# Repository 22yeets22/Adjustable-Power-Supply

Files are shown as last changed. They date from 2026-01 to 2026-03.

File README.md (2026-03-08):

<div align="center"> 
<h1>Adjustable Power Supply</h1>
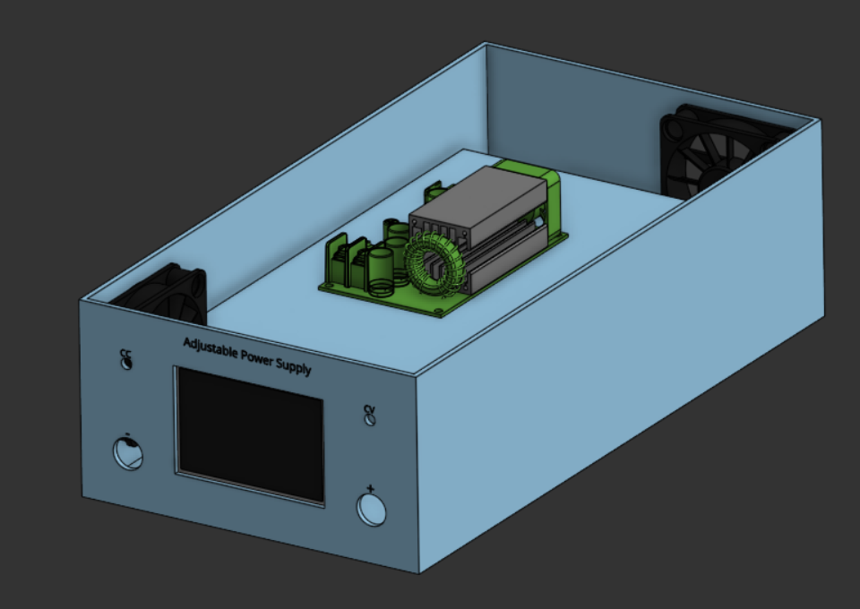
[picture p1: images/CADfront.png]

<h4>A cheap 600W adjustable power supply that supports 2.5-38V, 1-20A</h4>
</div>
<hr>

## About

This project is a high-power **bench power supply** capable of delivering **2.5–38V and up to 20A (≈600W)**.
This project allows you to easily test out components that require specific voltages and currents. The power supply is housed in a custom 3D-printed enclosure and includes active cooling and safety components like a circuit breaker and proper power distribution.

### How to Use

1. First wire up the project like in the wiring diagrams:
2. 3d print the cad case + lid, fit the parts in it
3. Plug the AC power cable into the IEC input and turn on the rocker switch.
4. Adjust the voltage and current, connect your device or circuit to the front banana jacks and monitor the output in real time.

### Motivation

This projects creates a **powerful, feature-rich lab power supply at a much lower cost** that allows you to control many precise devices at your will.

## CAD

[Go check out all the cad files!](CAD/)
<br>
[The rest of the cad images are here](images/)

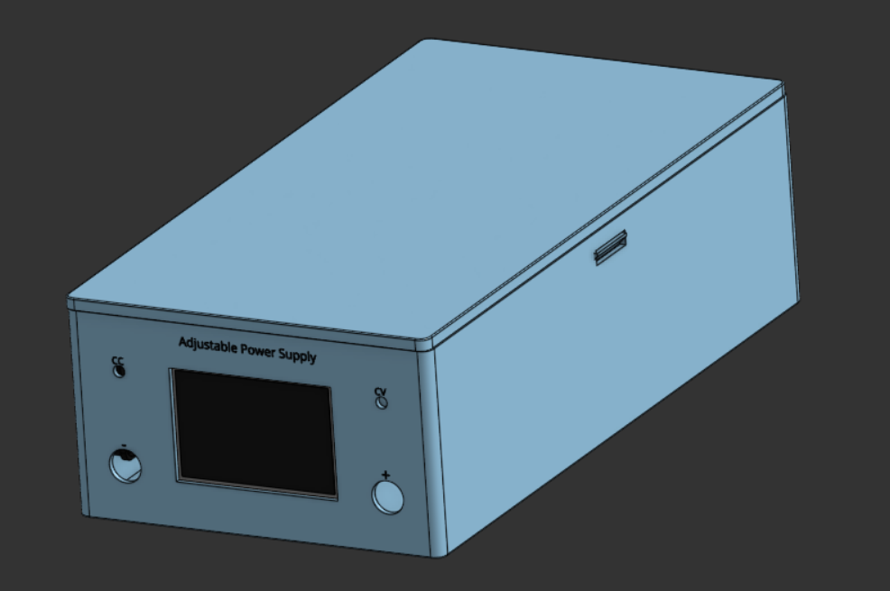
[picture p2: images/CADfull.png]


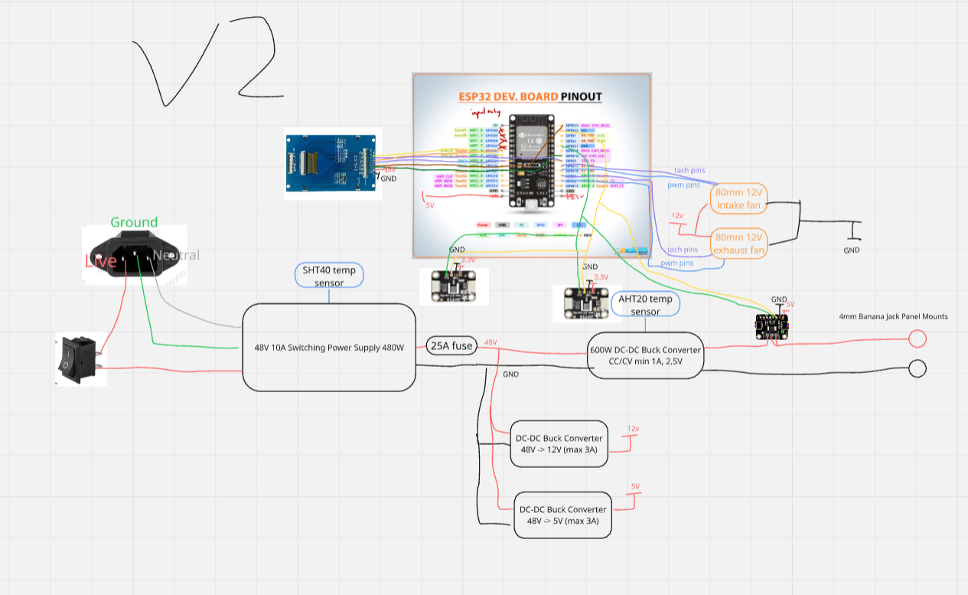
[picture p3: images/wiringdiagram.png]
Wiring Diagram

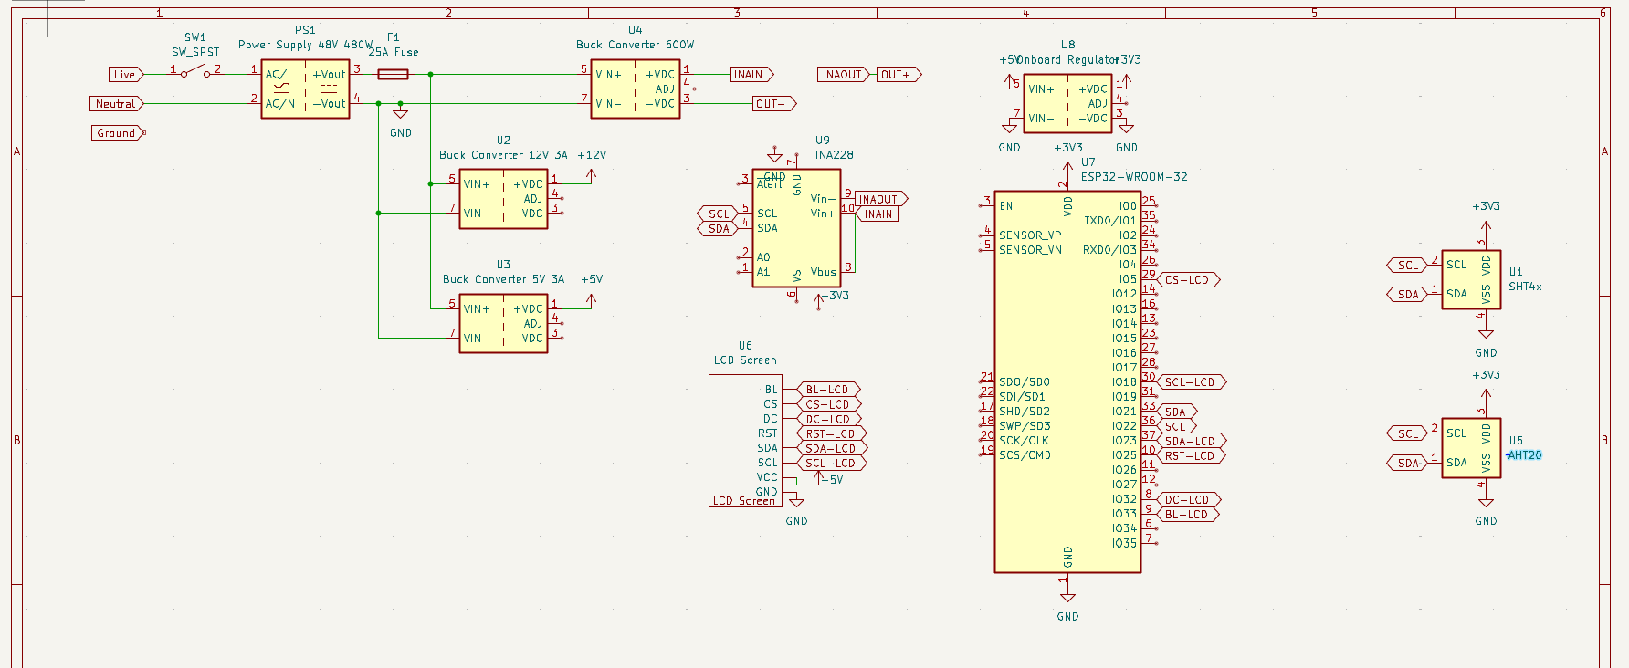
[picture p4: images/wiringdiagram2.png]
Wiring Diagram in KiCad


## BOM

> [!IMPORTANT]
> **Find the CSV format in [BOM.csv](/BOM.csv)**

### Cooling

- 1x of 60x60x10mm PWM Fan (Delta EFB0612HHA), TYPE standard 4pin/6010/EFB0612HHA, PRICE $3.96: https://www.aliexpress.com/item/2255800737378210.html
- 1x of 60x60x10mm PWM Fan (ADDA AD06012HX10AB00), TYPE Standard 4PIN PWM/black/NO RGB, PRICE $5.98: https://www.aliexpress.com/item/2251832835370376.html
- 1x of 50pcs/lot Aluminum Heatsink 8.8\*8.8\*5mm Electronic Chip Radiator Cooler w/ Thermal for IC,3D Printer, TYPE N/A, PRICE $2.42: https://www.aliexpress.com/item/2251832663311102.html

### Sensors + Modules

- 1x of SHT40 Temperature & Humidity Sensor Module, TYPE SHT40/China Mainland, PRICE $2.14: https://www.aliexpress.com/item/3256809091535018.html
- 1x of AHT20 + BMP280 Temp/Humidity/Pressure Sensor, TYPE Module, PRICE $1.63: https://www.aliexpress.com/item/3256806795952050.html
- 1x of ESP32 WROOM-32 Dev Board (USB-C), TYPE 1PCS-CP2102 TYPE-C, PRICE $0.99: https://www.aliexpress.com/item/3256805767190776.html
- 1x of INA228 Voltage/Current/Power Monitor Module, TYPE 228 welding, PRICE $5.70: https://www.aliexpress.com/item/3256810323201401.html
- 1x of 3.5" TFT LCD Screen (ST7796, 320x480), TYPE N/A, PRICE $7.56: https://www.aliexpress.com/item/3256809650697406.html
- 1x of Adjustable Buck Converter 60V 3A, TYPE 2-34V, PRICE $3.33: https://www.aliexpress.com/item/3256806811379418.html
- 1x of Buck Converter 60V 3A (5V Output), TYPE 5V, PRICE $3.25: https://www.aliexpress.com/item/3256806811379418.html
- 1x of Buck Converter 60V 3A (12V Output), TYPE 12V, PRICE $3.34: https://www.aliexpress.com/item/3256806811379418.html
- 1x of 600W CC/CV Buck Converter (12–75V Input), TYPE N/A, PRICE $11.66: https://www.aliexpress.com/item/3256807619950116.html

### Power + Wires

- 1x of 5Pcs Circuit Breaker Overload Protector Switch Fuse 3A 4A 5A 8A 10A 12A 15A 18A 20A 25A 30A Resettable 220V with Waterproof Cap, TYPE 5pcs/25A, PRICE $5.42: https://www.aliexpress.com/item/3256806057525580.html
- 1x of IEC C13 AC Power Cable (USA Plug, 1.2m), TYPE USA, PRICE $3.50: https://www.aliexpress.com/item/3256807060355465.html
- 1x of IEC C14 Panel Mount AC Socket, TYPE Type 4/China Mainland, PRICE $1.34: https://www.aliexpress.com/item/3256808473935736.html
- 1x of 4mm Banana Jack Panel Mount (Red), TYPE Red/1PCS, PRICE $1.34: https://www.aliexpress.com/item/3256805937948099.html
- 1x of 4mm Banana Jack Panel Mount (Black), TYPE black/1PCS, PRICE $1.26: https://www.aliexpress.com/item/3256805937948099.html
- 1x of Banana Plug to Alligator Clip Test Leads (20A, 90cm), TYPE N/A, PRICE $3.05: https://www.aliexpress.com/item/3256806675649321.html
- 1x of KCD1 Rocker Switch SPST, TYPE KCD1 15X20mm/5PCS, PRICE $2.40: https://www.aliexpress.com/item/3256808591861621.html
- 1x of 22 AWG Silicone Wire (4 colors, 25ft each), TYPE 22 gauge silicone wire each color 25ft, PRICE $9.98: https://www.amazon.com/gp/product/B07HGT44XY/
- 1x of 48V 10A Switching Power Supply (480W), TYPE N/A, PRICE $26.99: https://www.amazon.com/gp/product/B096VJMQFM/

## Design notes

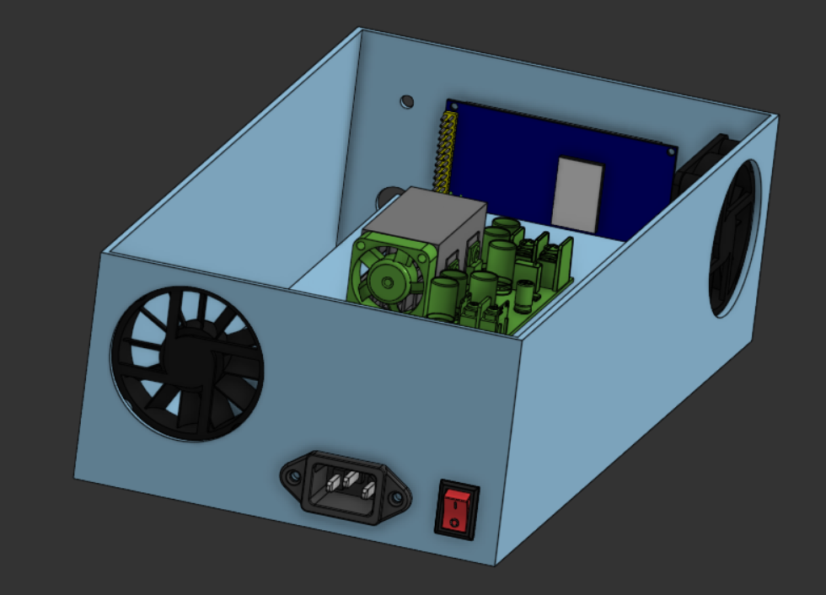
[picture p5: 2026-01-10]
images/CADback.png

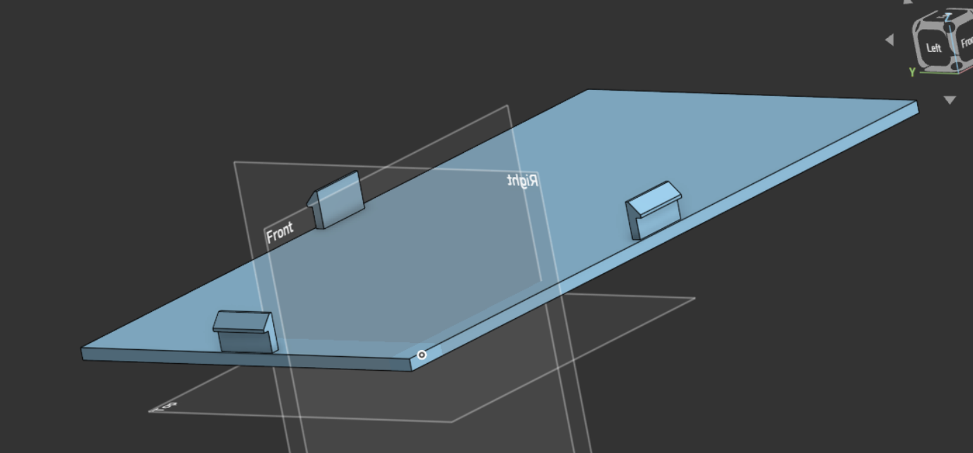
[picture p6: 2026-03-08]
images/lid.png

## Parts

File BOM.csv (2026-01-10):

Category | Quantity | Part Name | Type | Unit Price (USD) | Link
Cooling | 1 | 60x60x10mm PWM Fan (Delta EFB0612HHA) | standard 4pin/6010/EFB0612HHA | 3.96 | https://www.aliexpress.com/item/2255800737378210.html
Cooling | 1 | 60x60x10mm PWM Fan (ADDA AD06012HX10AB00) | Standard 4PIN PWM/black/NO RGB | 5.98 | https://www.aliexpress.com/item/2251832835370376.html
Cooling | 1 | Aluminum Heatsink 8.8x8.8x5mm (50pcs lot) | N/A | 2.42 | https://www.aliexpress.com/item/2251832663311102.html
Sensors + Modules | 1 | SHT40 Temperature & Humidity Sensor Module | SHT40/China Mainland | 2.14 | https://www.aliexpress.com/item/3256809091535018.html
Sensors + Modules | 1 | AHT20 + BMP280 Temp/Humidity/Pressure Sensor | Module | 1.63 | https://www.aliexpress.com/item/3256806795952050.html
Sensors + Modules | 1 | ESP32 WROOM-32 Dev Board (USB-C) | 1PCS-CP2102 TYPE-C | 0.99 | https://www.aliexpress.com/item/3256805767190776.html
Sensors + Modules | 1 | INA228 Voltage/Current/Power Monitor Module | 228 welding | 5.70 | https://www.aliexpress.com/item/3256810323201401.html
Sensors + Modules | 1 | 3.5 inch TFT LCD Screen (ST7796 320x480) | N/A | 7.56 | https://www.aliexpress.com/item/3256809650697406.html
Sensors + Modules | 1 | Adjustable Buck Converter 60V 3A | 2-34V | 3.33 | https://www.aliexpress.com/item/3256806811379418.html
Sensors + Modules | 1 | Buck Converter 60V 3A (5V Output) | 5V | 3.25 | https://www.aliexpress.com/item/3256806811379418.html
Sensors + Modules | 1 | Buck Converter 60V 3A (12V Output) | 12V | 3.34 | https://www.aliexpress.com/item/3256806811379418.html
Sensors + Modules | 1 | 600W CC/CV Buck Converter (12–75V Input) | N/A | 11.66 | https://www.aliexpress.com/item/3256807619950116.html
Power + Wires | 1 | Circuit Breaker Overload Protector Switch Fuse (5pcs) | 5pcs/25A | 5.42 | https://www.aliexpress.com/item/3256806057525580.html
Power + Wires | 1 | IEC C13 AC Power Cable (USA Plug 1.2m) | USA | 3.50 | https://www.aliexpress.com/item/3256807060355465.html
Power + Wires | 1 | IEC C14 Panel Mount AC Socket | Type 4/China Mainland | 1.34 | https://www.aliexpress.com/item/3256808473935736.html
Power + Wires | 1 | 4mm Banana Jack Panel Mount (Red) | Red/1PCS | 1.34 | https://www.aliexpress.com/item/3256805937948099.html
Power + Wires | 1 | 4mm Banana Jack Panel Mount (Black) | black/1PCS | 1.26 | https://www.aliexpress.com/item/3256805937948099.html
Power + Wires | 1 | Banana Plug to Alligator Clip Test Leads (20A 90cm) | N/A | 3.05 | https://www.aliexpress.com/item/3256806675649321.html
Power + Wires | 1 | KCD1 Rocker Switch SPST | KCD1 15X20mm/5PCS | 2.40 | https://www.aliexpress.com/item/3256808591861621.html
Power + Wires | 1 | 22 AWG Silicone Wire (4 colors 25ft each) | 22 gauge silicone wire each color 25ft | 9.98 | https://www.amazon.com/gp/product/B07HGT44XY/
Power + Wires | 1 | 48V 10A Switching Power Supply (480W) | N/A | 26.99 | https://www.amazon.com/gp/product/B096VJMQFM/

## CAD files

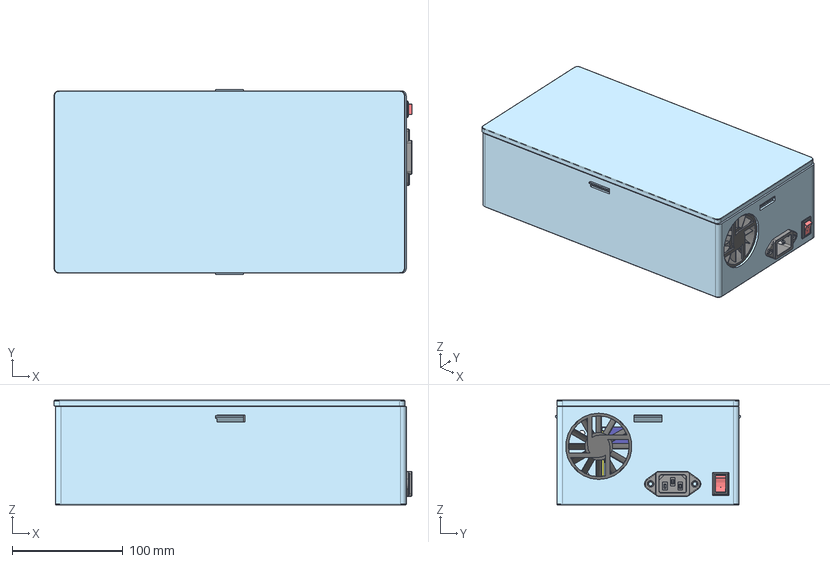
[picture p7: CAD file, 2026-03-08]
CAD - Full Assembly.step
323.9 x 167.6 x 94.6 mm
buck converter DC12-75V 25Ac 600w (Solid) x 44
LCD
Konektor36pin
MICRO_2pin_header__02

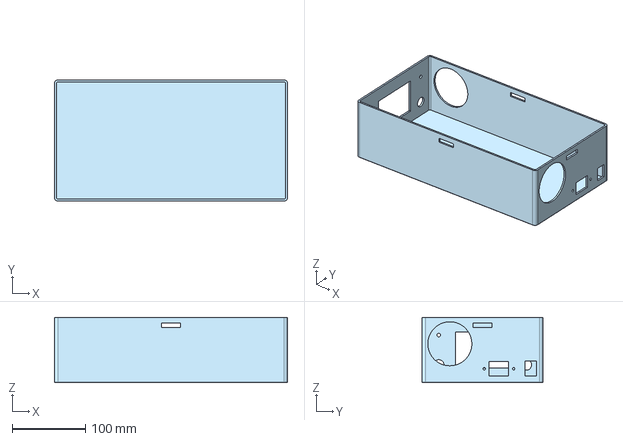
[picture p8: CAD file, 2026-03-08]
CAD/Adjustable Power Supply - Case.step
317.5 x 165.1 x 88.9 mm

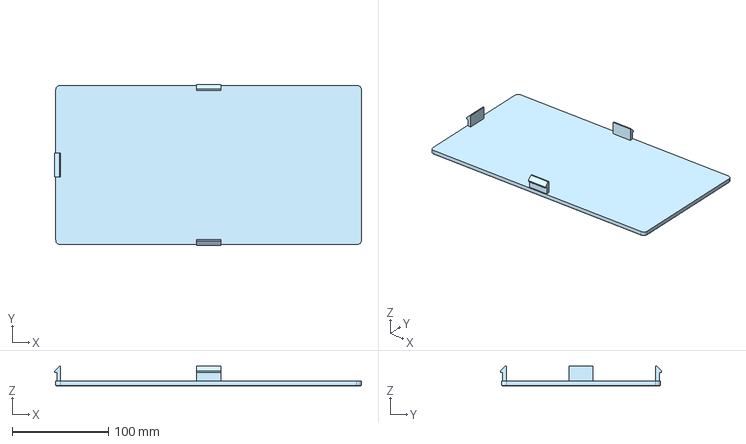
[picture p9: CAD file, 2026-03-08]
CAD/Adjustable Power Supply - Lid.step
318.8 x 167.6 x 20.3 mm

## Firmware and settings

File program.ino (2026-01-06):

#include <Wire.h>
#include <TFT_eSPI.h>  // https://github.com/Bodmer/TFT_eSPI/
#include <Adafruit_INA228.h>  // https://github.com/adafruit/Adafruit_INA228/
#include <Adafruit_AHTX0.h>  // https://github.com/adafruit/Adafruit_AHTX0/
#include <Adafruit_SHT4x.h>  // https://github.com/adafruit/Adafruit_SHT4X/
#include <PID_v1.h>  // https://github.com/br3ttb/Arduino-PID-Library/

// ------------------- PIN DEFINITIONS -------------------
#define INTAKE_PWM_PIN   16
#define INTAKE_TACH_PIN  17
#define EXHAUST_PWM_PIN   2
#define EXHAUST_TACH_PIN  4

#define I2C_SDA        21
#define I2C_SCL        22

// ------------------- CONSTANTS -------------------
const float TARGET_TEMP = 37.5;
const float WARN_TEMP   = 50.0;
const float CRIT_TEMP   = 55.0;
const float WARN_CURRENT = 15.0;
const float CRIT_CURRENT = 20.0;
const float WARN_VOLTAGE = 35.0;
const float CRIT_VOLTAGE = 40.0;
const float WARN_POWER = 400.0;
const float CRIT_POWER = 450.0;
const float WARN_FAN_SPEED = 900.0;  // pwm signal
const float CRIT_FAN_SPEED = 1000.0;

const uint32_t UPDATE_MS = 2000; // update every 0.5hz bc temp sensors slow
const uint32_t TACH_INTERVAL_MS = 1000;

// ------------------- GLOBAL OBJECTS -------------------
TFT_eSPI tft = TFT_eSPI();
Adafruit_INA228 ina;
Adafruit_AHTX0 aht20;
Adafruit_SHT4x sht40;

double temperature;
double humidity;
double fanPWM; // PID Output but pid
double fanTargetTemp = TARGET_TEMP;

double Kp = 40.0, Ki = 5.0, Kd = 1.0; // 10-bit PWM range
// input, output, target, kp, ki, kd, i have no clue
PID fanPID(&temperature, &fanPWM, &fanTargetTemp, Kp, Ki, Kd, DIRECT);

volatile uint32_t fan1Pulses = 0;
volatile uint32_t fan2Pulses = 0;

uint32_t lastUpdate = 0;
uint32_t lastTachCalc = 0;
float fan1RPM = 0;
float fan2RPM = 0;

// fan failure stuff
bool fan1Failed = false;
bool fan2Failed = false;
const int MIN_RPM_THRESHOLD = 100; // RPM below this is considered a fail if PWM high 
const int MIN_PWM_THRESHOLD = 200; // PWM above this is fail if RPM low


// ------------------- TACH INTERRUPTS -------------------
void IRAM_ATTR fan1TachISR() { fan1Pulses++; }
void IRAM_ATTR fan2TachISR() { fan2Pulses++; }

// ------------------- SETUP -------------------
void setup() {
  Serial.begin(115200);
  Wire.begin(I2C_SDA, I2C_SCL);

  tft.init();
  tft.setRotation(1);
  tft.fillScreen(TFT_BLACK);
  tft.setTextColor(TFT_WHITE, TFT_BLACK);
  tft.setTextSize(2);
  tft.setCursor(10, 10);
  tft.println("SYSTEM INITIALIZING...");

  // Sensors init
  if (!ina.begin()) { Serial.println("INA228 Not Found"); }
  // Calibration: the INA228 has a 0.002 ohm shunt
  ina.setShunt(0.002, 25.0);  // 2mohm, 25a random number
  ina.setVoltageConversionTime(INA228_TIME_1052_us);  // 1052 microseconds time to measure voltage
  ina.setCurrentConversionTime(INA228_TIME_1052_us);
  
  if (!aht20.begin()) { Serial.println("AHT20 Not Found"); }
  if (!sht40.begin()) { Serial.println("SHT40 Not Found"); }

  sht40.setPrecision(SHT4X_HIGH_PRECISION);  // theres also medium and low

  // Fans PWM (ESP32 Core 3.0+ syntax)
  ledcAttach(INTAKE_PWM_PIN, 25000, 10); // Pin, Freq, Resolution
  ledcAttach(EXHAUST_PWM_PIN, 25000, 10);

  // Tach pins
  pinMode(INTAKE_TACH_PIN, INPUT_PULLUP);
  pinMode(EXHAUST_TACH_PIN, INPUT_PULLUP);
  attachInterrupt(digitalPinToInterrupt(INTAKE_TACH_PIN), fan1TachISR, FALLING);
  attachInterrupt(digitalPinToInterrupt(EXHAUST_TACH_PIN), fan2TachISR, FALLING);

  // PID
  fanPID.SetOutputLimits(0, 1023); // Match 10-bit resolution
  fanPID.SetMode(AUTOMATIC);
}

void updateTemps() {
  sensors_event_t humidity_aht, humidity_sht, temp_aht, temp_sht;
  aht20.getEvent(&humidity_aht, &temp_aht);
  sht40.getEvent(&humidity_sht, &temp_sht);

  humidity = (humidity_aht.relative_humidity + humidity_sht.relative_humidity) * 0.5;  // average humidity
  temperature = max(temp_aht.temperature, temp_sht.temperature);  // higher temperature
}

// ------------------- LOOP -------------------
void loop() {
  uint32_t now = millis();

  if (now - lastTachCalc >= TACH_INTERVAL_MS) {
    // Fan stuff
    detachInterrupt(digitalPinToInterrupt(INTAKE_TACH_PIN));
    detachInterrupt(digitalPinToInterrupt(EXHAUST_TACH_PIN));
    
    fan1RPM = (fan1Pulses / 2.0) * (60000.0 / (now - lastTachCalc));
    fan2RPM = (fan2Pulses / 2.0) * (60000.0 / (now - lastTachCalc));
    
    fan1Pulses = 0;
    fan2Pulses = 0;
    lastTachCalc = now;
    
    attachInterrupt(digitalPinToInterrupt(INTAKE_TACH_PIN), fan1TachISR, FALLING);
    attachInterrupt(digitalPinToInterrupt(EXHAUST_TACH_PIN), fan2TachISR, FALLING);

    // Fan Failure Detection
    fan1Failed = (fanPWM > MIN_PWM_THRESHOLD && fan1RPM < MIN_RPM_THRESHOLD);  // if pwm high but no speed
    fan2Failed = (fanPWM > MIN_PWM_THRESHOLD && fan2RPM < MIN_RPM_THRESHOLD);
  }

  if (now - lastUpdate >= UPDATE_MS) {
    // UPDATE SCREEN
    lastUpdate = now;

    updateTemps();
    fanPID.Compute();

    // Fan 1 (Intake) is 15% faster than Fan 2 (Exhaust)
    double fan1PWM_Output = fanPWM * 1.15;
    double fan2PWM_Output = fanPWM;

    // Constrain to 10-bit limit (0-1023)
    if (fan1PWM_Output > 1023) fan1PWM_Output = 1023;
    if (fan2PWM_Output > 1023) fan2PWM_Output = 1023;

    ledcWrite(INTAKE_PWM_PIN, (uint32_t)fan1PWM_Output);
    ledcWrite(EXHAUST_PWM_PIN, (uint32_t)fan2PWM_Output);

    float voltage = ina.getBusVoltage_V();
    float current = ina.getCurrent_mA() / 1000.0;
    float power   = ina.getPower_mW() / 1000.0;

    displayUpdate(voltage, current, power);
  }

  delay(5);
}

uint16_t getColor(float value, float warn, float crit) {
    if (value >= crit) return TFT_RED;
    if (value >= warn) return TFT_YELLOW;
    return TFT_WHITE;
}

// ------------------- FUNCTIONS -------------------
void displayUpdate(float voltage, float current, float power) {
  tft.setCursor(0, 0);
  tft.setTextColor(TFT_WHITE, TFT_BLACK);
  
  tft.setTextColor(getColor(voltage, WARN_VOLTAGE, CRIT_VOLTAGE), TFT_BLACK);
  tft.printf("Voltage: %5.2f V \n", voltage);

  tft.setTextColor(getColor(current, WARN_CURRENT, CRIT_CURRENT), TFT_BLACK);
  tft.printf("Current: %5.2f A \n", current);

  tft.setTextColor(getColor(power, WARN_POWER, CRIT_POWER), TFT_BLACK);
  tft.printf("Power:   %5.2f W \n\n", power);

  tft.setTextColor(getColor(temperature, WARN_TEMP, CRIT_TEMP), TFT_BLACK);
  tft.printf("Temp: %4.1f C \n", temperature);

  tft.setTextColor(TFT_WHITE, TFT_BLACK);
  tft.printf("Humidity: %4.1f rH \n", humidity);

  tft.setTextColor(getColor(fanPWM, WARN_FAN_SPEED, CRIT_FAN_SPEED), TFT_BLACK);
  tft.printf("Fan Speed: %4.0f%%    \n", (fanPWM / 1023.0 * 100.0));
  
  // Display RPM with failure color-coding
  tft.setTextColor(fan1Failed ? TFT_RED : TFT_GREEN, TFT_BLACK);
  tft.printf("F1 (In):  %4.0f RPM %s\n", fan1RPM, fan1Failed ? "FAIL" : "OK  ");
  
  tft.setTextColor(fan2Failed ? TFT_RED : TFT_GREEN, TFT_BLACK);
  tft.printf("F2 (Out): %4.0f RPM %s\n\n", fan2RPM, fan2Failed ? "FAIL" : "OK  ");

  // Status Alerts
  tft.setTextColor(TFT_WHITE, TFT_BLACK);
  if (fan1Failed || fan2Failed) {
    tft.setTextColor(TFT_RED, TFT_BLACK);
    tft.println("!! FAN FAILURE !! ");
  } else if (current > CRIT_CURRENT || temperature > CRIT_TEMP) {
    tft.setTextColor(TFT_RED, TFT_BLACK);
    tft.println("!! CRITICAL !!    ");
  } else {
    tft.setTextColor(TFT_GREEN, TFT_BLACK);
    tft.println("SYSTEM NOMINAL    ");
  }
}

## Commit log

2025-12-29 Add parts list to README for power supply project
    Added a detailed parts list for the adjustable power supply project, including input, cooling, and output components with links and prices.
2025-12-29 Update parts list with new switch and fan details
2025-12-29 Add image to README for adjustable power supply
2025-12-29 Rename Screenshot 2025-12-29 092018.png to CAD.png
2025-12-29 Add image reference for CAD in README
2025-12-29 add cad
    [Adjustable Power Supply.step]
2025-12-29 Create BOM.csv with component details
    Added a Bill of Materials (BOM) with components and pricing.
    [BOM.csv]
2025-12-29 Rename Screenshot 2025-12-29 100741.png to wiringdiagram.png
2025-12-29 Add wiring diagram to README
    Added wiring diagram image to README.
2026-01-04 new cAD!!
2026-01-06 Initialize program with sensor and display setup
2026-01-10 Update power supply specs and parts list
    Updated the maximum output current from 15A to 20A. Added additional parts to the list including sensors, modules, and power wires.
2026-01-10 Fix link to BOM.csv in README.md
2026-01-10 Update BOM.csv with additional components
    Added new components to the Bill of Materials including various cooling fans, sensors, and power wires.
    [BOM.csv]
2026-01-10 Fix type description for power supply in README
    Corrected the type description for the 48V 10A Switching Power Supply.
2026-01-10 UPDATE CAD, WIRING DIAGRAM IMAGES, CAD IMAGES
    [Adjustable Power Supply.step]
2026-01-10 Fix formatting of heatsink entry in README
2026-03-08 Update power supply description from 500W to 600W
2026-03-08 add cads + images
    [Adjustable Power Supply - Case.step, Adjustable Power Supply - Full Assembly.step, Adjustable Power Supply - Lid.step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]
2026-03-08 add new cad, add to readme
    [Adjustable Power Supply - Full Assembly copy.step, CAD - Full Assembly.step]
